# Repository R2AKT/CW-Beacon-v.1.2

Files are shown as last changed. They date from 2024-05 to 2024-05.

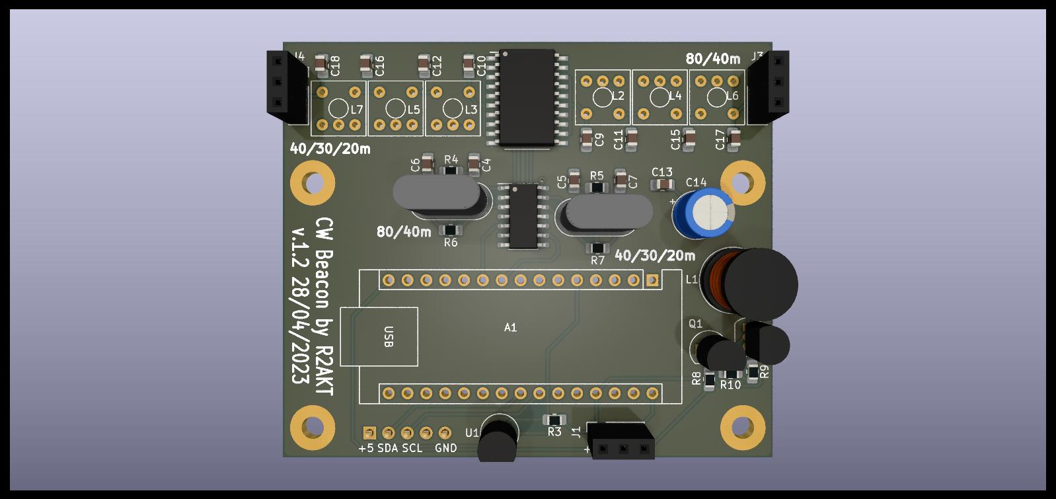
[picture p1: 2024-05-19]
CW_Beacon_v.1.2_front.jpg

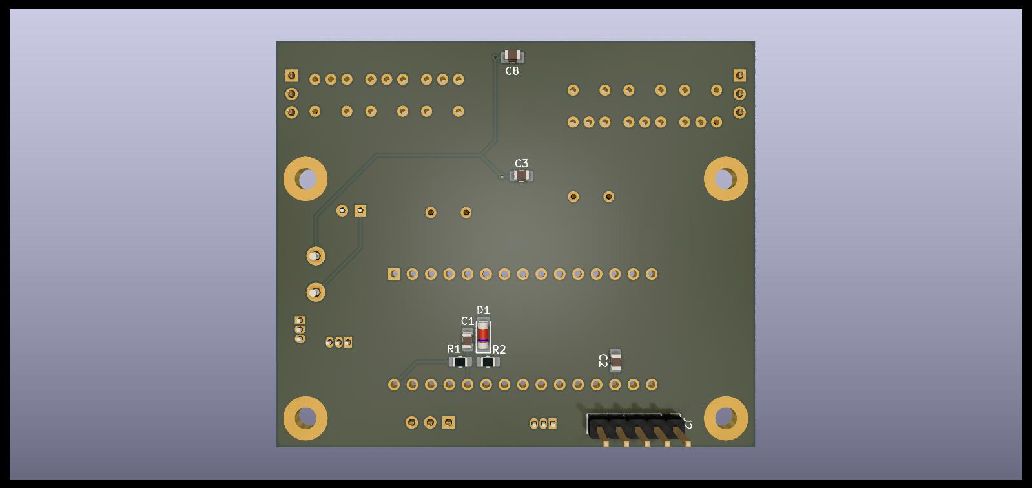
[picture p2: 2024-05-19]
CW_Beacon_v.1.2_back.jpg

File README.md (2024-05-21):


# CW_Beacon
2-х канальный QPR CW автономный маяк (возможна работа только одного канала).
В основе Arduino Nano, генераторная часть построена на кварцевом резонаторе
и стандартной логике. В качестве оконечного каскада используется магистральный
шинный формирователь. На выходе стоят ФНЧ 7-го порядка.

Маяк передаёт заранее заложенное сообщение, при наличии термодатчика DS18B20 и/или резистивного 
делителя напряжения можно добавлять измеренные значения в сообщение.

Подробное описание можно найти на сайте <a href="https://r2akt.ru/%d0%bf%d1%80%d0%be%d0%b5%d0%ba%d1%82%d1%8b/%d0%b0%d0%b2%d1%82%d0%be%d0%bd%d0%be%d0%bc%d0%bd%d1%8b%d0%b9-cw-%d0%bc%d0%b0%d1%8f%d0%ba-%d0%bd%d0%b0-%d0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" target=_blank>https://r2akt.ru/%d0%bf%d1%80%d0%be%d0%b5%d0%ba%d1%82%d1%8b/%d0%b0%d0%b2%d1%82%d0%be%d0%bd%d0%be%d0%bc%d0%bd%d1%8b%d0%b9-cw-%d0%bc%d0%b0%d1%8f%d0%ba-%d0%bd%d0%b0-%d0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</a>

## Баги и обратная связь
При нахождении багов создавайте **Issue**.  
Библиотека открыта для доработки и ваших **Pull Request**'ов!

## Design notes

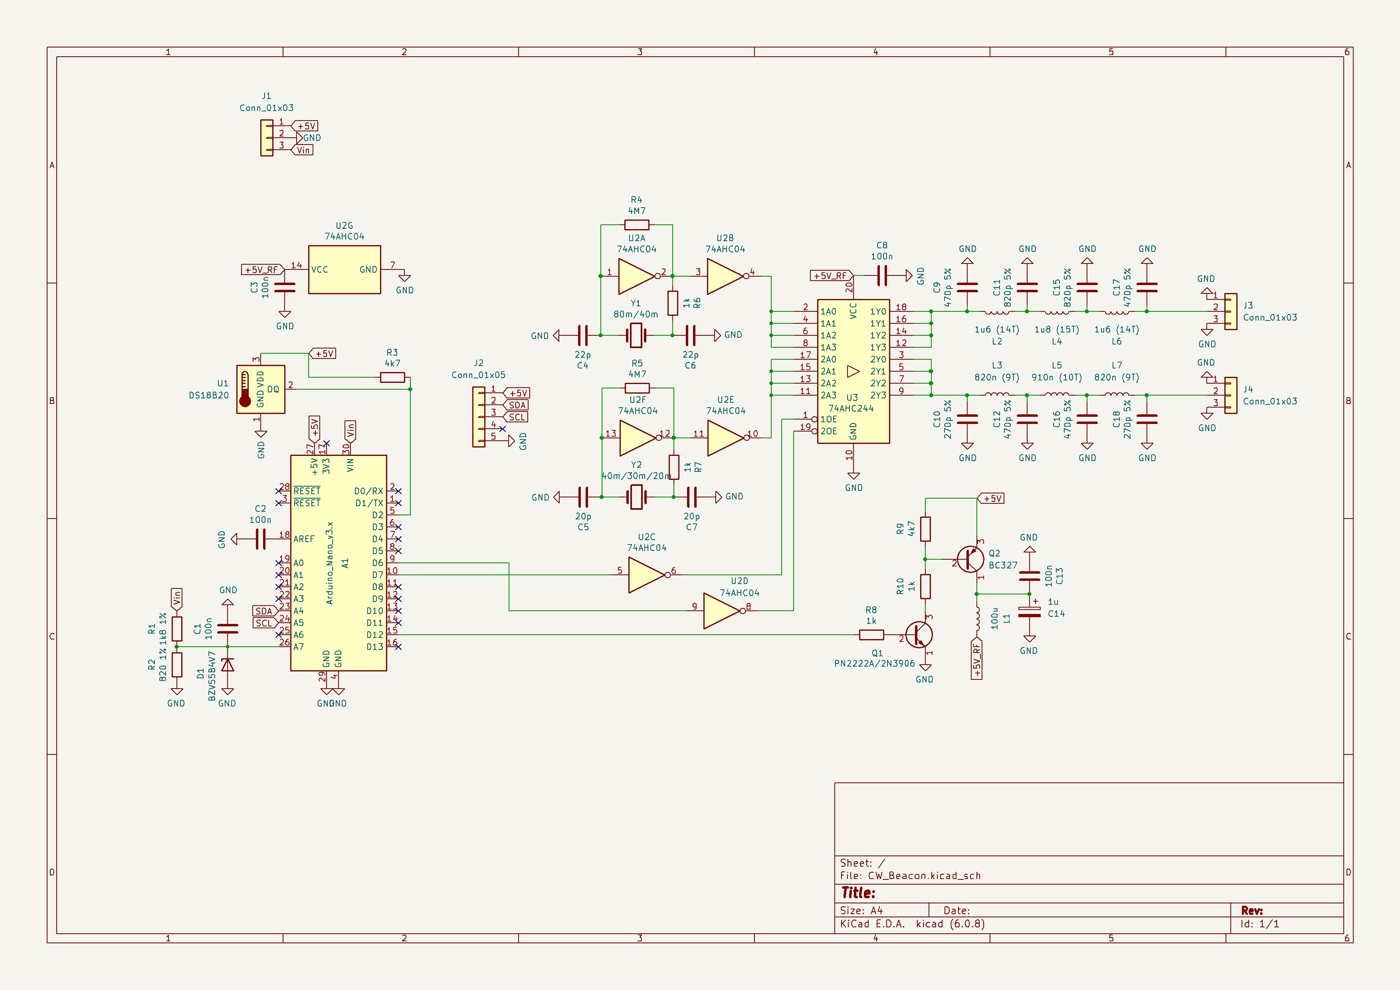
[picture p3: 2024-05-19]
Schematic_v.1.2.jpg

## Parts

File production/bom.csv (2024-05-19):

Designator | Footprint | Quantity | Value | LCSC Part #
A1 | Arduino_Nano | 1 | Arduino_Nano_v3.x
C1, C13, C2, C3, C8 | C_0805_2012Metric_Pad1.18x1.45mm_HandSolder | 5 | 100n
C10, C18 | C_0805_2012Metric_Pad1.18x1.45mm_HandSolder | 2 | 270p 5%
C11, C15 | C_0805_2012Metric_Pad1.18x1.45mm_HandSolder | 2 | 820p 5%
C12, C16, C17, C9 | C_0805_2012Metric_Pad1.18x1.45mm_HandSolder | 4 | 470p 5%
C14 | CP_Radial_D6.3mm_P2.50mm | 1 | 1u
C4, C6 | C_0805_2012Metric_Pad1.18x1.45mm_HandSolder | 2 | 22p
C5, C7 | C_0805_2012Metric_Pad1.18x1.45mm_HandSolder | 2 | 20p
D1 | D_MiniMELF | 1 | BZV55B4V7
J1, J3, J4 | PinSocket_1x03_P2.54mm_Vertical | 3 | Conn_01x03
J2 | PinHeader_1x05_P2.54mm_Vertical | 1 | Conn_01x05
L1 | L_Radial_D8.7mm_P5.00mm_Fastron_07HCP | 1 | 100u
L2, L6 | TNT_Variable_Induction_7x7 | 2 | 1u6 (14T)
L3, L7 | TNT_Variable_Induction_7x7 | 2 | 820n (9T)
L4 | TNT_Variable_Induction_7x7 | 1 | 1u8 (15T)
L5 | TNT_Variable_Induction_7x7 | 1 | 910n (10T)
Q1 | TO-92_Inline | 1 | PN2222A/2N3906
Q2 | TO-92_Inline | 1 | BC327
R1 | R_0805_2012Metric_Pad1.20x1.40mm_HandSolder | 1 | 1k8 1%
R10, R6, R7, R8 | R_0805_2012Metric_Pad1.20x1.40mm_HandSolder | 4 | 1k
R2 | R_0805_2012Metric_Pad1.20x1.40mm_HandSolder | 1 | 820 1%
R3, R9 | R_0805_2012Metric_Pad1.20x1.40mm_HandSolder | 2 | 4k7
R4, R5 | R_0805_2012Metric_Pad1.20x1.40mm_HandSolder | 2 | 4M7
U1 | TO-92_Inline | 1 | DS18B20
U2 | SOIC-14_3.9x8.7mm_P1.27mm | 1 | 74AHC04
U3 | SO-20_12.8x7.5mm_P1.27mm | 1 | 74AHC244
Y1 | Crystal_HC49-U_Vertical | 1 | 80m/40m
Y2 | Crystal_HC49-U_Vertical | 1 | 40m/30m/20m

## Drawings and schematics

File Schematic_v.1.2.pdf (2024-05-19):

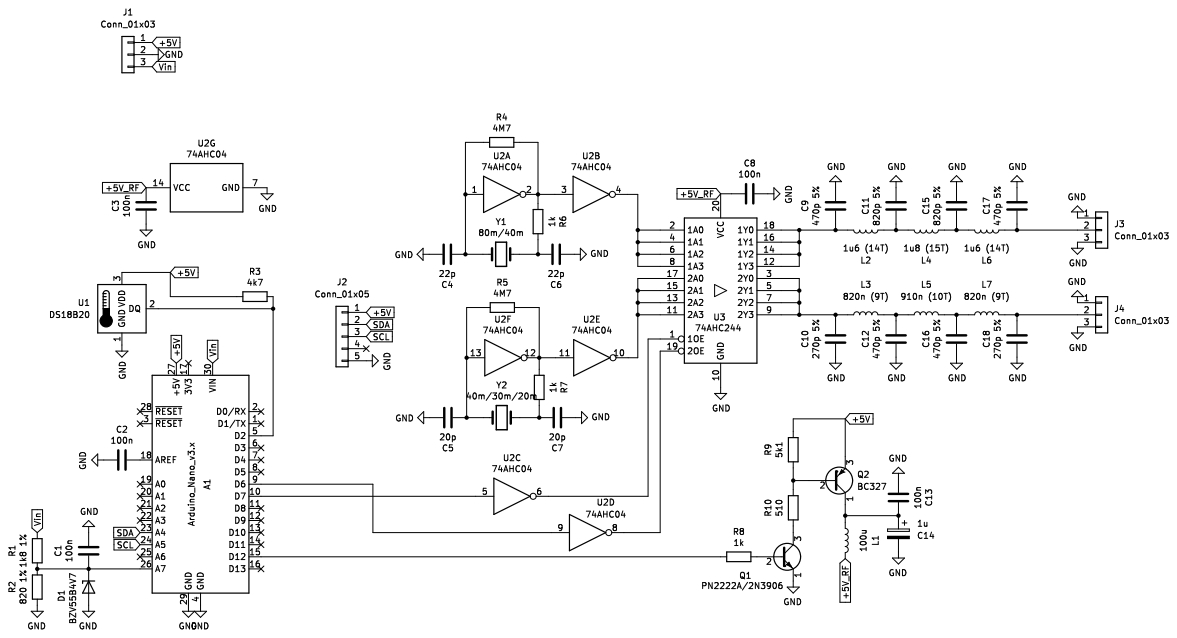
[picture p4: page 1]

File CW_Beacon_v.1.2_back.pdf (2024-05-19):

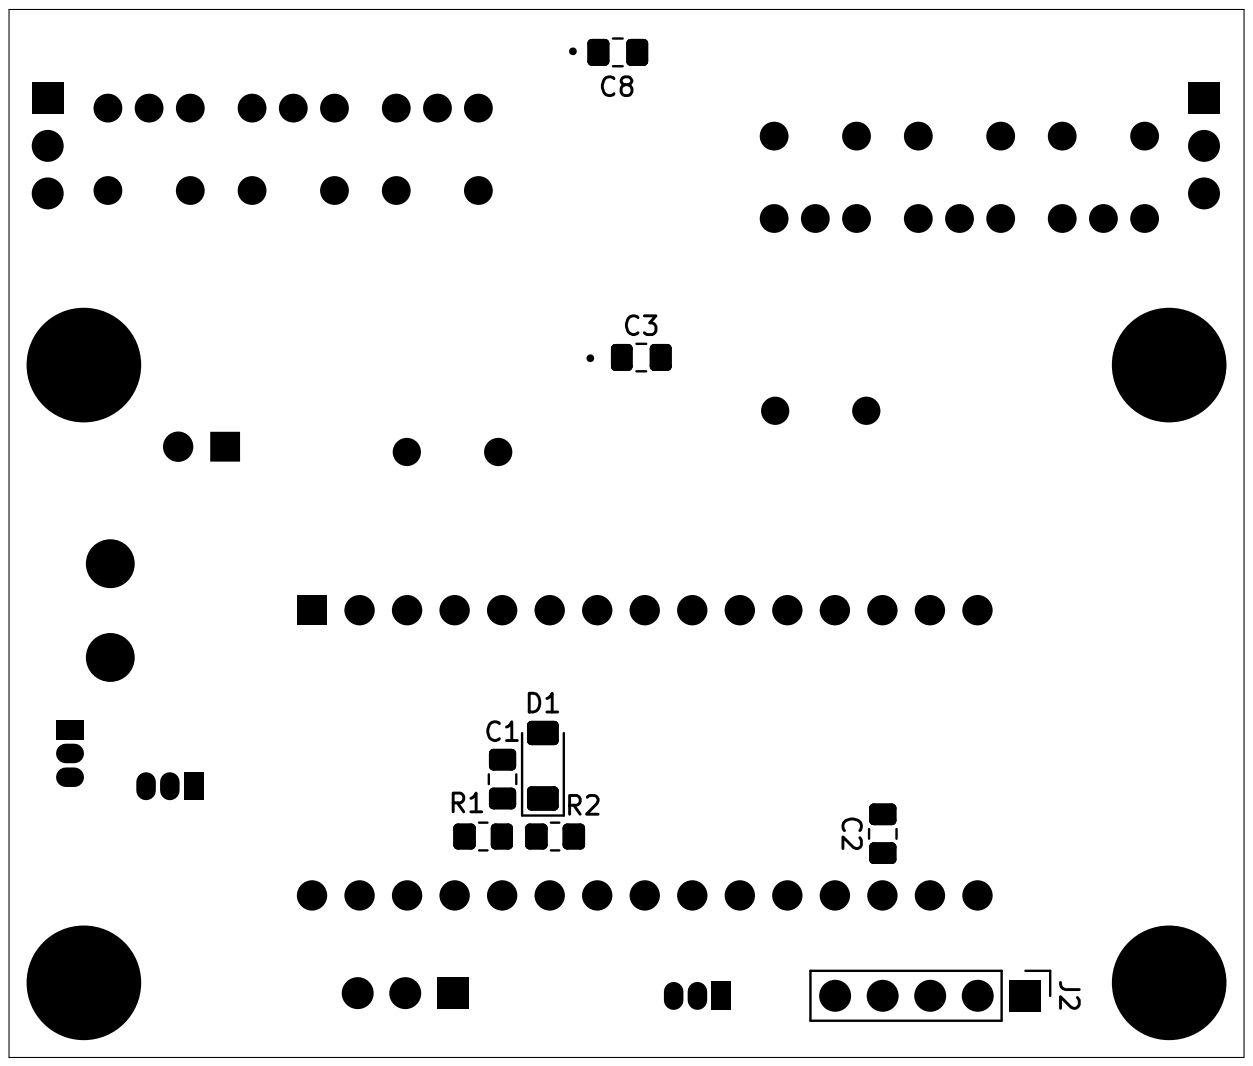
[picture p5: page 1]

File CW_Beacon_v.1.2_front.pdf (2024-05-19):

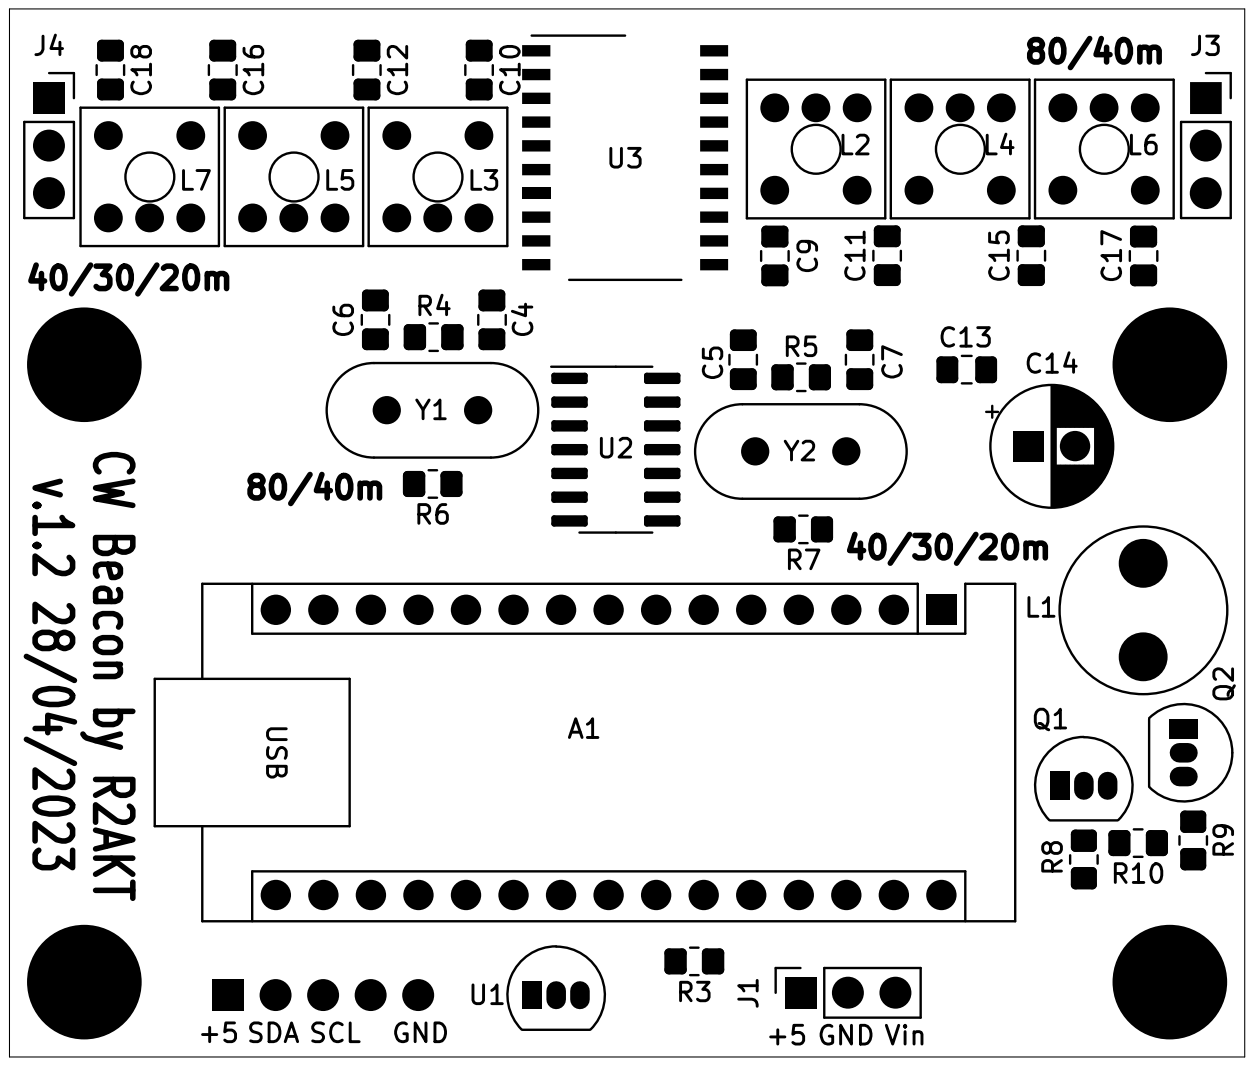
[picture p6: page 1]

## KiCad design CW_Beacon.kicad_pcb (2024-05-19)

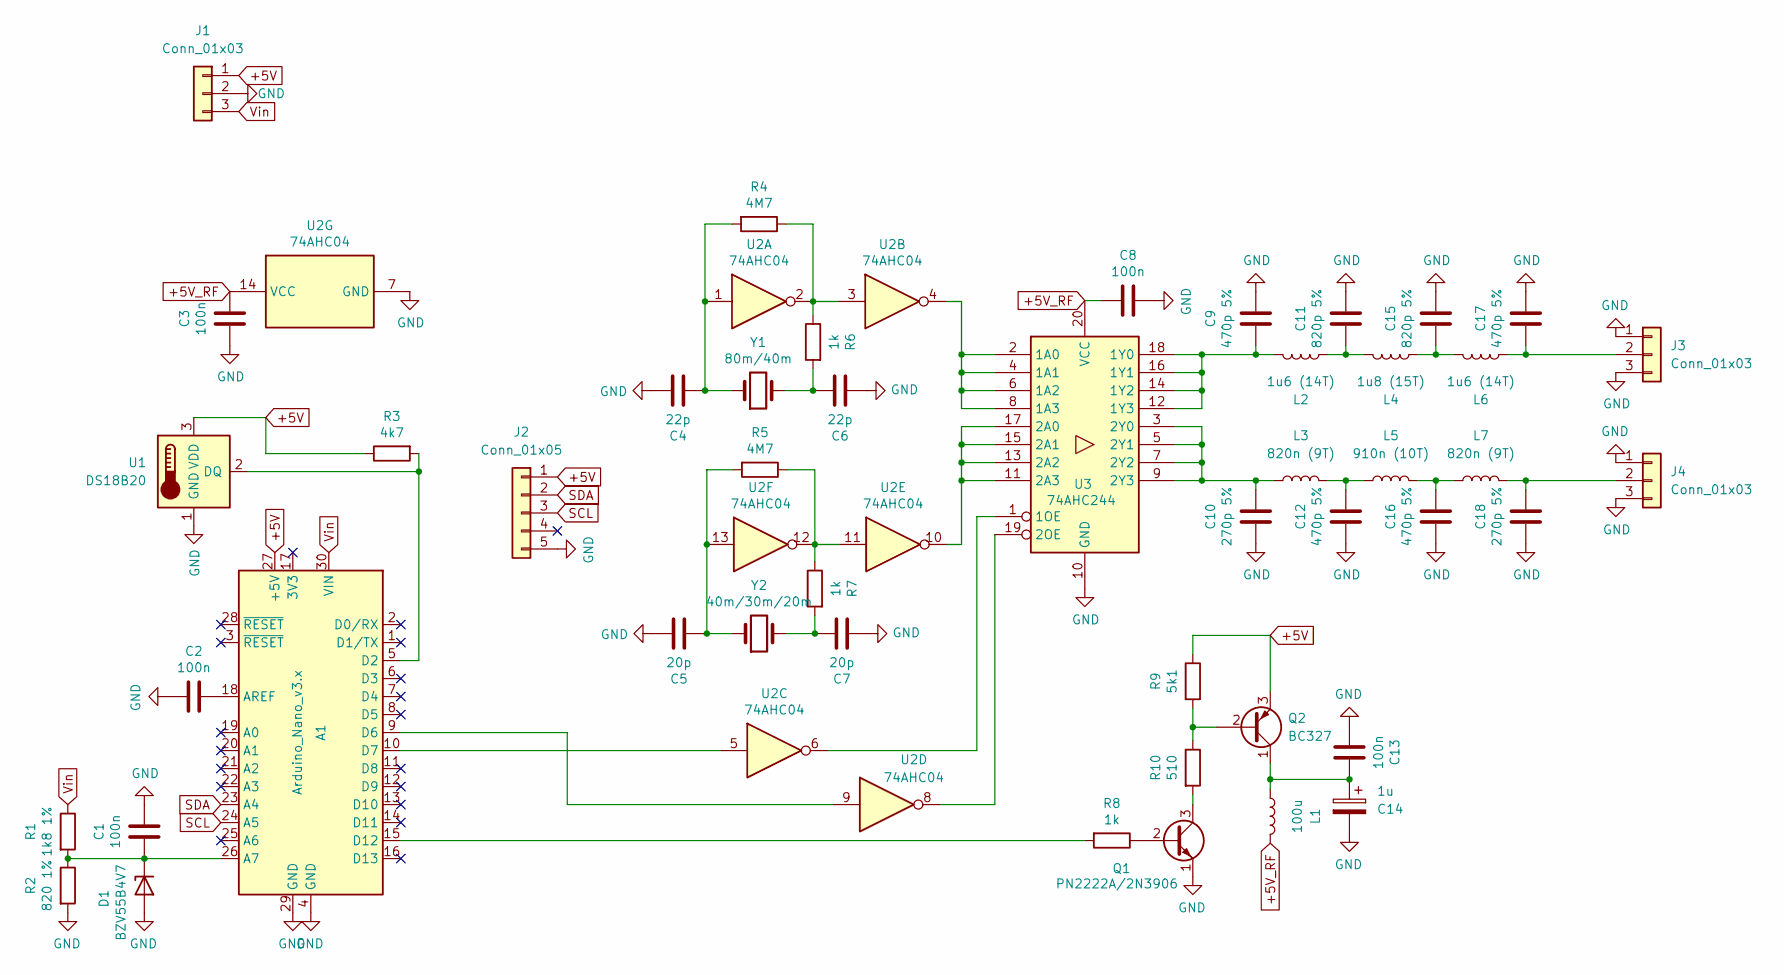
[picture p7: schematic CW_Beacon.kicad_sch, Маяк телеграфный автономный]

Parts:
A1: Arduino_Nano_v3.x; Arduino_Nano
C1, C2, C3, C8, C13: 100n; C_0805_2012Metric_Pad1.18x1.45mm_HandSolder
C4, C6: 22p; C_0805_2012Metric_Pad1.18x1.45mm_HandSolder
C5, C7: 20p; C_0805_2012Metric_Pad1.18x1.45mm_HandSolder
C9, C12, C16, C17: 470p 5%; C_0805_2012Metric_Pad1.18x1.45mm_HandSolder
C10, C18: 270p 5%; C_0805_2012Metric_Pad1.18x1.45mm_HandSolder
C11, C15: 820p 5%; C_0805_2012Metric_Pad1.18x1.45mm_HandSolder
C14: 1u; CP_Radial_D6.3mm_P2.50mm
D1: BZV55B4V7; D_MiniMELF
J1, J3, J4: Conn_01x03; PinSocket_1x03_P2.54mm_Vertical
J2: Conn_01x05; PinHeader_1x05_P2.54mm_Vertical
L1: 100u; L_Radial_D8.7mm_P5.00mm_Fastron_07HCP
L2, L6: 1u6 (14T); TNT_Variable_Induction_7x7
L3, L7: 820n (9T); TNT_Variable_Induction_7x7
L4: 1u8 (15T); TNT_Variable_Induction_7x7
L5: 910n (10T); TNT_Variable_Induction_7x7
Q1: PN2222A/2N3906; TO-92_Inline
Q2: BC327; TO-92_Inline
R1: 1k8 1%; R_0805_2012Metric_Pad1.20x1.40mm_HandSolder
R2: 820 1%; R_0805_2012Metric_Pad1.20x1.40mm_HandSolder
R3: 4k7; R_0805_2012Metric_Pad1.20x1.40mm_HandSolder
R4, R5: 4M7; R_0805_2012Metric_Pad1.20x1.40mm_HandSolder
R6, R7, R8: 1k; R_0805_2012Metric_Pad1.20x1.40mm_HandSolder
R9: 5k1; R_0805_2012Metric_Pad1.20x1.40mm_HandSolder
R10: 510; R_0805_2012Metric_Pad1.20x1.40mm_HandSolder
U1: DS18B20; TO-92_Inline
U2: 74AHC04; SOIC-14_3.9x8.7mm_P1.27mm
U3: 74AHC244; SO-20_12.8x7.5mm_P1.27mm
Y1: 80m/40m; Crystal_HC49-U_Vertical
Y2: 40m/30m/20m; Crystal_HC49-U_Vertical

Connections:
+5V: A1.27 (+5V), J1.1, J2.1, Q2.3 (E), R3.1, R9.1, U1.3 (VDD)
+5V_RF: C3.1, C8.1, L1.2, U2.14 (VCC), U3.20 (VCC)
GND: A1.4 (GND), A1.29 (GND), C1.2, C2.2, C3.2, C4.1, C5.1, C6.2, C7.2, C8.2, C9.1, C10.1, C11.1, C12.1, C13.2, C14.2, C15.1, C16.1, C17.1, C18.1, D1.2 (A), J1.2, J2.5, J3.1, J3.3, J4.1, J4.3, Q1.1 (E), R2.2, U1.1 (GND), U2.7 (GND), U3.10 (GND)
unnamed: A1.26 (A7), C1.1, D1.1 (K), R1.2, R2.1
unnamed: A1.18 (AREF), C2.1
unnamed: A1.5 (D2), R3.2, U1.2 (DQ)
unnamed: A1.9 (D6), U2.9
unnamed: A1.10 (D7), U2.5
unnamed: A1.15 (D12), R8.2
unnamed: C4.2, R4.2, U2.1, Y1.1
unnamed: C5.2, R5.2, U2.13, Y2.1
unnamed: C6.1, R6.2, Y1.2
unnamed: C7.1, R7.2, Y2.2
unnamed: C11.2, L2.2, L4.1
unnamed: C12.2, L3.2, L5.1
unnamed: C15.2, L4.2, L6.1
unnamed: C16.2, L5.2, L7.1
unnamed: C17.2, J3.2, L6.2
unnamed: C18.2, J4.2, L7.2
unnamed: Q1.2 (B), R8.1
unnamed: Q1.3 (C), R10.2
unnamed: Q2.2 (B), R9.2, R10.1
unnamed: C13.1, C14.1, L1.1, Q2.1 (C)
unnamed: R4.1, R6.1, U2.2, U2.3
unnamed: R5.1, R7.1, U2.11, U2.12
unnamed: U2.4, U3.2 (1A0), U3.4 (1A1), U3.6 (1A2), U3.8 (1A3)
unnamed: U2.6, U3.1 (1OE)
unnamed: C9.2, L2.1, U3.12 (1Y3), U3.14 (1Y2), U3.16 (1Y1), U3.18 (1Y0)
unnamed: U2.10, U3.11 (2A3), U3.13 (2A2), U3.15 (2A1), U3.17 (2A0)
unnamed: U2.8, U3.19 (2OE)
unnamed: C10.2, L3.1, U3.3 (2Y0), U3.5 (2Y1), U3.7 (2Y2), U3.9 (2Y3)
SCL: A1.24 (A5), J2.3
SDA: A1.23 (A4), J2.2
Vin: A1.30 (VIN), J1.3, R1.1

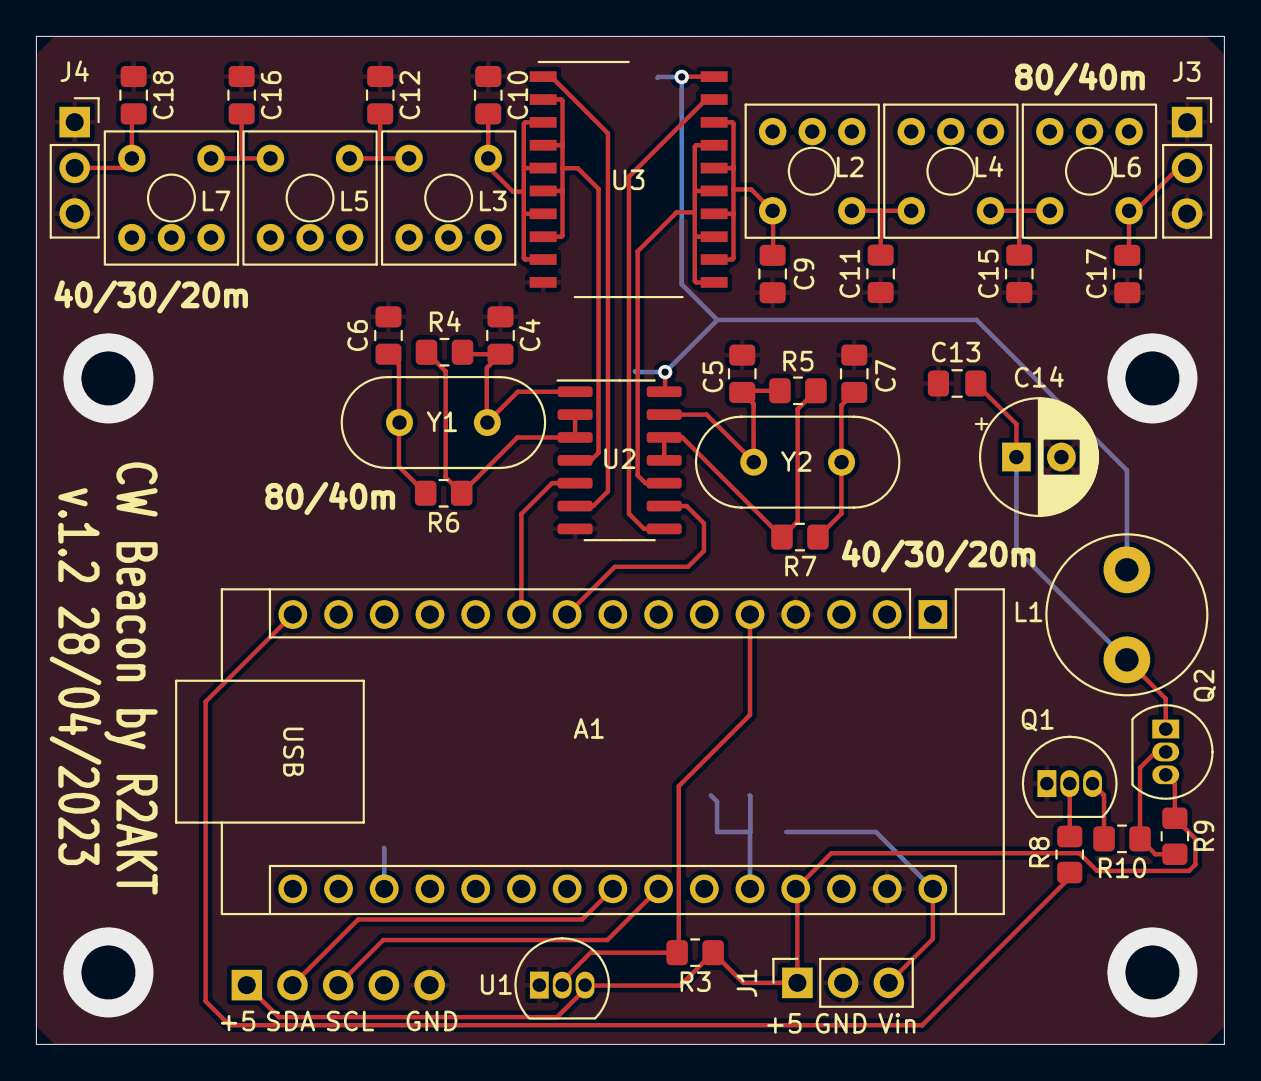
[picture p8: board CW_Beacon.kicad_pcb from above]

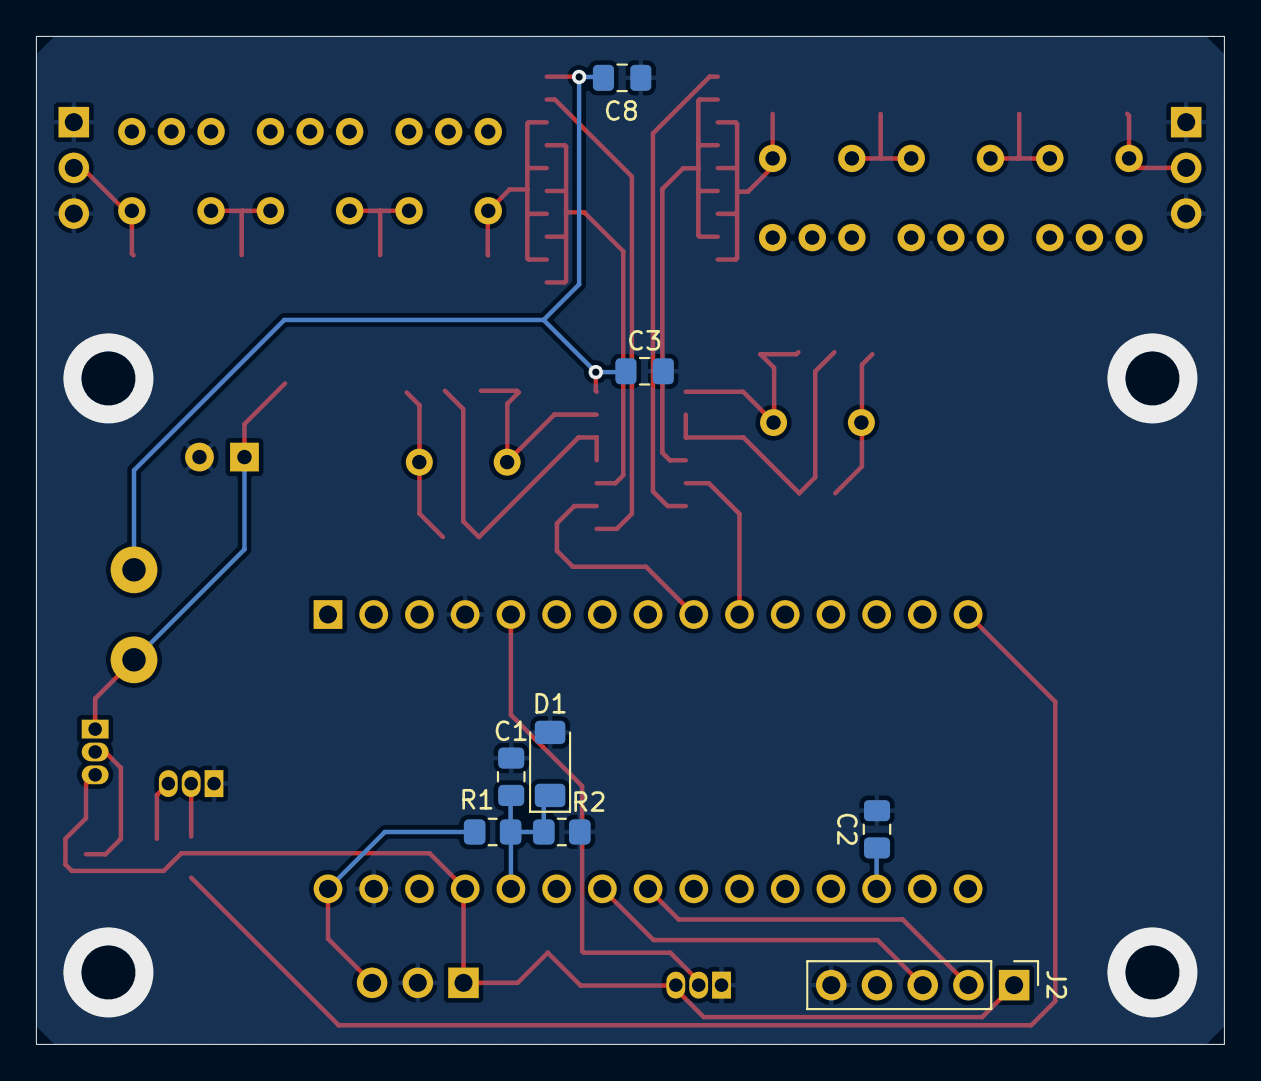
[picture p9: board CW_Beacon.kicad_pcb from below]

Board: 2 copper layers, 66.0 x 56.0 mm, 48 parts (8 on the bottom side), 34 nets.

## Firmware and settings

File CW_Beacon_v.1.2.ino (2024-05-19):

#include "LowPower.h"

#include <Watchdog.h>
Watchdog watchdog;

#define PIN_TX1 7
#define PIN_EN_TX1 12

#define Dual_Channel
//#define DFCW_TX1
#ifdef Dual_Channel
  //#define DFCW_TX2
#endif

// #ifdef DFCW_TX1
//   #define DF_TX1 8
// #endif

#ifdef Dual_Channel
  #define PIN_TX2 6
  #define PIN_EN_TX2 12
  
  // #ifdef DFCW_TX2
  //   #define DF_TX2 9
  // #endif
#endif

#define TempSensor
#ifdef TempSensor
  #include <OneWire.h>
  #include <DallasTemperature.h>
  #define ONE_WIRE_BUS 2
  OneWire oneWire (ONE_WIRE_BUS); // Setup a oneWire instance to communicate with any OneWire devices (not just Maxim/Dallas temperature ICs)
  DallasTemperature sensors (&oneWire); // Pass our oneWire reference to Dallas Temperature.
#endif

//#define VoltageControl
#ifdef VoltageControl
  #define ADC_pin A7
#endif


#define CW_WPM 16
uint16_t duration = 60000/(CW_WPM*50);    // Morse code typing speed in WPM

static char Channel_Num = 0;

#define TimeInterval 5 // Beacon interval in seconds
#define TimeBeaconInterval 2 // Beacon interval in seconds between channel

String Base_CW__Message = "VVV de R2AKT/B KO85XW";   // Your base message

//----------
void _delay (unsigned long DelayTime) {
  for (unsigned int DelayCount = 0; DelayCount <= (DelayTime/SLEEP_15MS); DelayCount++) {
    LowPower.idle (SLEEP_15MS, ADC_OFF, TIMER2_OFF, TIMER1_OFF, TIMER0_OFF, SPI_OFF, USART0_OFF, TWI_OFF);
  }
}
//----------
void setup () {
  pinMode (PIN_TX1, OUTPUT);
  digitalWrite (PIN_TX1, LOW);
 #ifdef Dual_Channel
    pinMode (PIN_TX2, OUTPUT);
    digitalWrite (PIN_TX2, LOW);
 #endif

  #ifdef VoltageControl
    analogReference (DEFAULT); // ADC reference
  #endif
  
  pinMode (PIN_EN_TX1, OUTPUT);
  digitalWrite (PIN_EN_TX1, LOW);
  #ifdef Dual_Channel
    pinMode (PIN_EN_TX2, OUTPUT);
    digitalWrite (PIN_EN_TX2, LOW);
  #endif
  
  #ifdef TempSensor
    #ifdef DEBUG
      Serial.begin (9600);
      Serial.print ("Locating sensor devices...");
      sensors.begin();
      Serial.print ("Found ");
      Serial.print (sensors.getDeviceCount(), DEC);
      Serial.println (" devices.");
    #endif
  #endif

  // Setup watchdog
  watchdog.enable (Watchdog::TIMEOUT_8S);
}
//----------
void loop () {
  String cw_message = Base_CW__Message;
  
  //
  // do {
  //   digitalWrite (PIN_EN_TX1, HIGH); // Power On Generator 1
  //   digitalWrite (PIN_EN_TX2, HIGH); // Power On Generator 2
  //   digitalWrite (PIN_TX1, HIGH);
  //   digitalWrite (PIN_TX2, HIGH);
  //   digitalWrite (13, HIGH);
  // } while (1);
  //
  #ifdef TempSensor
    sensors.requestTemperatures(); // Send the command to get temperatures
    float tempC = sensors.getTempCByIndex(0);
    if (tempC != DEVICE_DISCONNECTED_C) {
      #ifdef DEBUG
        Serial.print("Temperature for the device 1 (index 0) is: ");
        Serial.println (tempC);
      #endif
      cw_message += " / Temp = " + String (tempC);
    } else {
      #ifdef DEBUG
        Serial.println("Error: Could not read temperature data");
        #endif
    }
  #endif

  #ifdef VoltageControl
  int Volt = analogRead (ADC_pin);
    cw_message += " / Volt = " + String ((float)(Volt*5)/1024);
  #endif
  
  #ifdef DEBUG
    Serial.println ();
  #endif

  cw_message.toUpperCase(); // Changes all letters to upper case

  digitalWrite (PIN_EN_TX1, HIGH); // Power On Generator 1
  Channel_Num = 1;
  delay (2000); // Wait generator
   
  cw (true);
  delay (2000);                         // Duration of the long signal at the end - in milliseconds

  cw (false);
  delay (1000);                          // Duration of the pause at the end after the long signal - in milliseconds
  
  cw_string_proc (cw_message);
  delay (500);                           // Duration of the break at the end before the long signal - in milliseconds

  cw (true);
  delay (2000);                         // Duration of the long signal at the end - in milliseconds

  cw(false);
  delay (1000);                          // Duration of the pause at the end after the long signal - in milliseconds

  Channel_Num = 0;
  digitalWrite (PIN_EN_TX1, LOW); // Power Off Generator 1
  
  #ifdef Dual_Channel
    for (int BeaconInterval = 0; BeaconInterval < TimeBeaconInterval; BeaconInterval++) {
      LowPower.idle (SLEEP_1S, ADC_OFF, TIMER2_OFF, TIMER1_OFF, TIMER0_OFF, SPI_OFF, USART0_OFF, TWI_OFF);
      watchdog.reset();
    }
    
    digitalWrite (PIN_EN_TX2, HIGH); // Power On Generator 2
    Channel_Num = 2;
    delay (2000); // Wait generator
     
    cw (true);
    delay (2000);                         // Duration of the long signal at the end - in milliseconds
  
    cw (false);
    delay (1000);                          // Duration of the pause at the end after the long signal - in milliseconds
    
    cw_string_proc (cw_message);
    delay (500);                           // Duration of the break at the end before the long signal - in milliseconds
  
    cw (true);
    delay (2000);                         // Duration of the long signal at the end - in milliseconds
  
    cw(false);
    delay (1000);                          // Duration of the pause at the end after the long signal - in milliseconds
  
    Channel_Num = 0;
    digitalWrite (PIN_EN_TX2, LOW); // Power Off Generator 2
  #endif

  for (int DelayCount = 0; DelayCount < TimeInterval; DelayCount++) {
    LowPower.idle (SLEEP_1S, ADC_OFF, TIMER2_OFF, TIMER1_OFF, TIMER0_OFF, SPI_OFF, USART0_OFF, TWI_OFF);
    watchdog.reset();
  }
}
//----------
void cw_string_proc (String str) {                      // Processing string to characters
  for (uint8_t j = 0; j < str.length (); j++)
    cw_char_proc (str[j]);
}
//----------
void cw_char_proc (char m) {                            // Processing characters to Morse symbols
  String s;

  if (m == ' ') {                                      // Pause between words
    word_space ();
    return;
  }

  if (m > 96)                                          // ACSII, case change a-z to A-Z
    if (m < 123)
      m -= 32;

  switch (m) {                                         // Morse
    case 'A': s = ".-#";     break;
    case 'B': s = "-...#";   break;
    case 'C': s = "-.-.#";   break;
    case 'D': s = "-..#";    break;
    case 'E': s = ".#";      break;
    case 'F': s = "..-.#";   break;
    case 'G': s = "--.#";    break;
    case 'H': s = "....#";   break;
    case 'I': s = "..#";     break;
    case 'J': s = ".---#";   break;
    case 'K': s = "-.-#";    break;
    case 'L': s = ".-..#";   break;
    case 'M': s = "--#";     break;
    case 'N': s = "-.#";     break;
    case 'O': s = "---#";    break;
    case 'P': s = ".--.#";   break;
    case 'Q': s = "--.-#";   break;
    case 'R': s = ".-.#";    break;
    case 'S': s = "...#";    break;
    case 'T': s = "-#";      break;
    case 'U': s = "..-#";    break;
    case 'V': s = "...-#";   break;
    case 'W': s = ".--#";    break;
    case 'X': s = "-..-#";   break;
    case 'Y': s = "-.--#";   break;
    case 'Z': s = "--..#";   break;

    case 'А': s = ".-#";     break;
    case 'Б': s = "-...#";   break;
    case 'В': s = ".--#";    break;
    case 'Г': s = "--.#";    break;
    case 'Д': s = "-..#";    break;
    case 'Е': s = ".#";      break;
    case 'Ё': s = ".#";      break;
    case 'Ж': s = "...-#";   break;
    case 'З': s = "--..#";   break;
    case 'И': s = "..#";     break;
    case 'Й': s = ".---#";   break;
    case 'К': s = "-.-#";    break;
    case 'Л': s = ".-..#";   break;
    case 'М': s = "--#";     break;
    case 'Н': s = "-.#";     break;
    case 'О': s = "---#";    break;
    case 'П': s = ".--.#";   break;
    case 'Р': s = ".-.#";    break;
    case 'С': s = "...#";    break;
    case 'Т': s = "-#";      break;    
    case 'У': s = "..-#";    break;
    case 'Ф': s = "..-.#";   break;
    case 'Х': s = "....#";   break;
    case 'Ц': s = "-.-.#";   break;
    case 'Ч': s = "---.#";   break;
    case 'Ш': s = "----#";   break;
    case 'Щ': s = "--.-#";   break;
    case 'Ь': s = "-..-#";   break;
    case 'Ы': s = "-.--#";   break;
    case 'Ъ': s = "-..-#";   break;
    case 'Э': s = "..-..#";   break;
    case 'Ю': s = "..--#";   break;
    case 'Я': s = ".-.-#";   break;

    case '1': s = ".----#";  break;
    case '2': s = "..---#";  break;
    case '3': s = "...--#";  break;
    case '4': s = "....-#";  break;
    case '5': s = ".....#";  break;
    case '6': s = "-....#";  break;
    case '7': s = "--...#";  break;
    case '8': s = "---..#";  break;
    case '9': s = "----.#";  break;
    case '0': s = "-----#";  break;

    case '-': s = "-....-#"; break;
    case '+': s = ".-.-.#"; break;
    case '=': s = "-...-#"; break;
    case '.': s = ".-.-.-#"; break;
    case ',': s = "--..--#"; break;
    case '?': s = "..--..#"; break;
    case '/': s = "-..-.#";  break;
    case ':': s = "---...#"; break;
    case '@': s = ".--.-.#"; break;
    case '%': s = "-..-.#"; break;
    case '(': s = "-.--.#"; break;
    case ')': s = "-.--.-#"; break;  
  }

  for (uint8_t i = 0; i < 7; i++) {
    switch (s[i]) {
      case '.': di ();  break;                          // di
      case '-': dah ();  break;                          // dah
      case '#': char_space (); return;                  // end of morse symbol
    }
  }
}
//----------
void di () {
  cw (true);                                            // TX di
  delay(duration);

  cw (false);                                           // stop TX di
  delay (duration);
}
//----------
void dah() {
  cw (true);                                            // TX dah
  delay (3 * duration);

  cw (false);                                           // stop TX dah
  delay (duration);
}
//----------
void char_space () {                                    // 3x, pause between letters
  delay  (2 * duration);                                 // 1x from end of character + 2x from the beginning of new character
}
//----------
void word_space() {                                    // 7x, pause between words
  delay (6 * duration);                                 // 1x from end of the word + 6x from the beginning of new word
}
//----------
void cw (bool state) {                                  // TX-CW, TX-LED
  watchdog.reset();
  if (state) {
    if (Channel_Num == 1) {
      digitalWrite (PIN_TX1, HIGH);
      digitalWrite (13, HIGH);
       #ifdef DFCW_TX1
        digitalWrite (DF_TX1, LOW);
      #endif
    }
    #ifdef Dual_Channel
      if (Channel_Num == 2) {
        digitalWrite (PIN_TX2, HIGH);
        digitalWrite (13, HIGH);
        #ifdef DFCW_TX2
          digitalWrite (DF_TX2, LOW);
        #endif
      }
    #endif
  } else {
    if (Channel_Num == 1) {
      #ifdef DFCW_TX1
        digitalWrite (DF_TX1, HIGH);
      #else
        digitalWrite (PIN_TX1, LOW);
        digitalWrite (13, LOW);
      #endif
    }
    #ifdef Dual_Channel
      if (Channel_Num == 2) {
        #ifdef DFCW_TX2
          digitalWrite (DF_TX2, HIGH);
        #else
          digitalWrite (PIN_TX2, LOW);
          digitalWrite (13, LOW);
        #endif
      }
    #endif
  }
}

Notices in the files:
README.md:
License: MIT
